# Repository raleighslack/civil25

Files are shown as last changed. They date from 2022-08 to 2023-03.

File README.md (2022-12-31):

# civil25 - An 8088 SBC  
A 8088 based SBC. 512k of RAM. 256k of ROM.

This is a simple 8088 based SBC that doesnt aim for any kind of PC compatibility. This is just generally a project to learn about the 8088 and other processors.

Current assembler in use is NASM. I am working on the **Currently in progress** goals listed below, as well as software to support it along the way.

## Current Parts List

- 1x 80c88 CPU
- 2x 74HCT373 D-type Octal Latch
- 1x 74HCT245 Bus Trancever
- 2x 74HCT138 3-to-8 Decoder
- 1x SST39SF020A Flash
- 1x AS6C4008 RAM
- 1x 82c55A PPI
- 1x 82c59 PIC
- 1x 555/8284 Clock Generator(And supporting circuitry)
- 1x YM3812 FM Sound
- 1x TL072 Op-Amp
- 1x Y3014B DAC
- 1x LCD
- 100000x Jumper Wires

# Completed

- Base Computer
- 82c55 I/O plus LCD
- YM3812
- Schematics

# Currently in progress

- 82c59 Programmable Interrupt Controller
- PS/2 Keyboard
- Video Card using SCN2674B
- Add SD Card
- Real Time Clock + Battery

# Future additions (Hardware)

- PCB - Mini ITX - Compatible with ATX PSU's
- Ethernet - Currently looking at the `W5100S-L`
- DMA Controller (82c57)
- Timer (82c53/82c54)
- CMOS RAM to maintain system settings

## Future Aditions (Software)

- C Compiler
- Make BIOS
- Make Kernel
- Make C Standard Library
- Make UNIX Operating System

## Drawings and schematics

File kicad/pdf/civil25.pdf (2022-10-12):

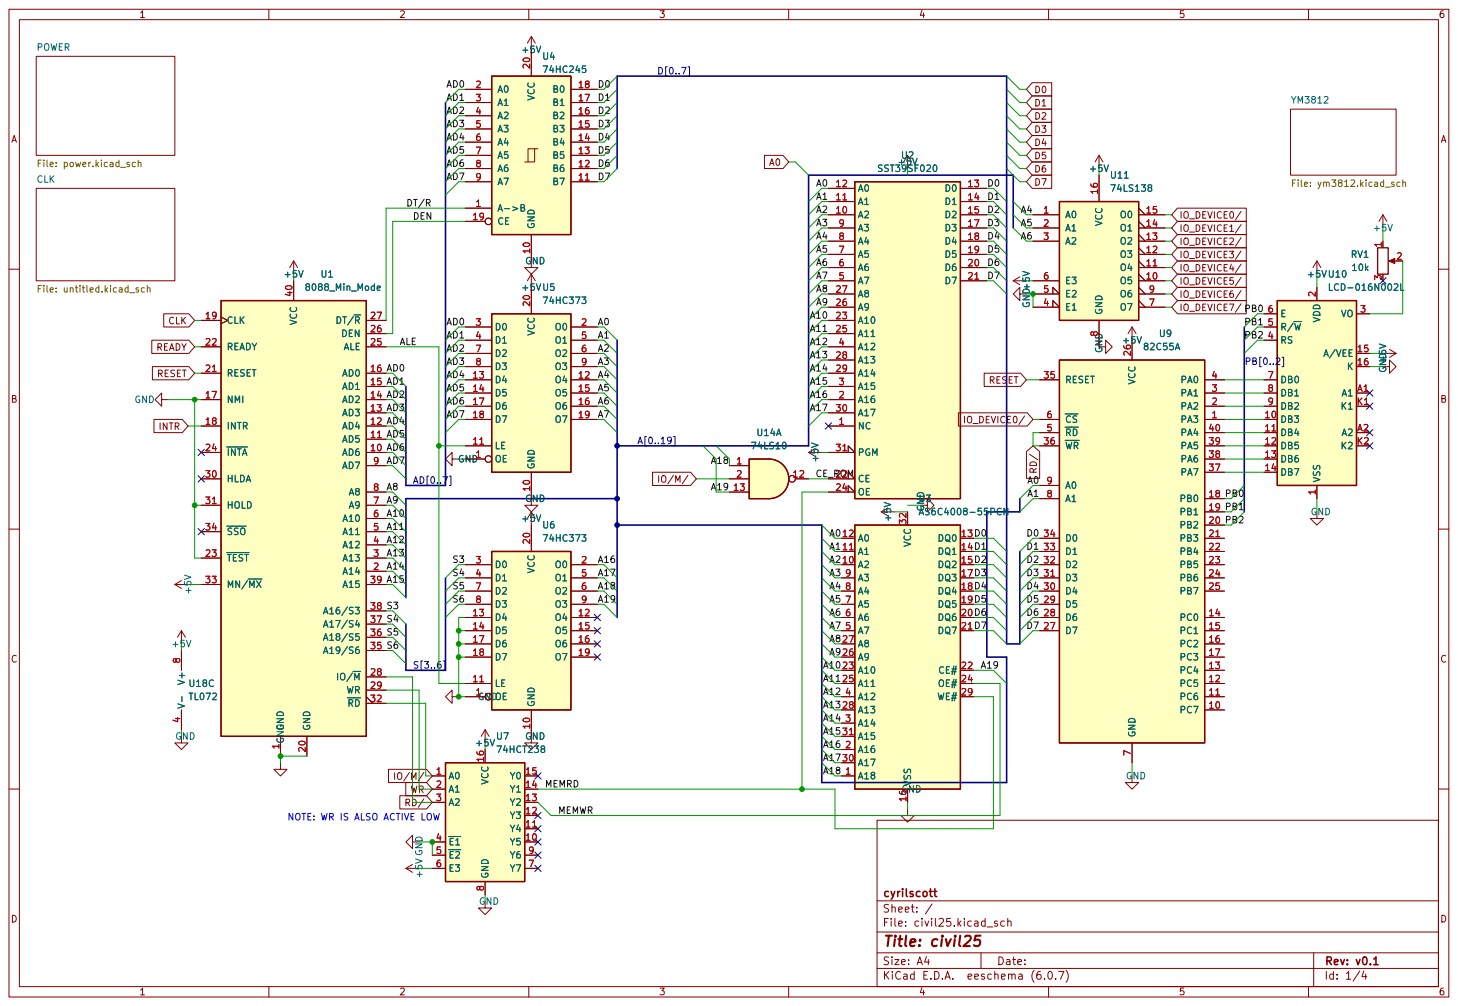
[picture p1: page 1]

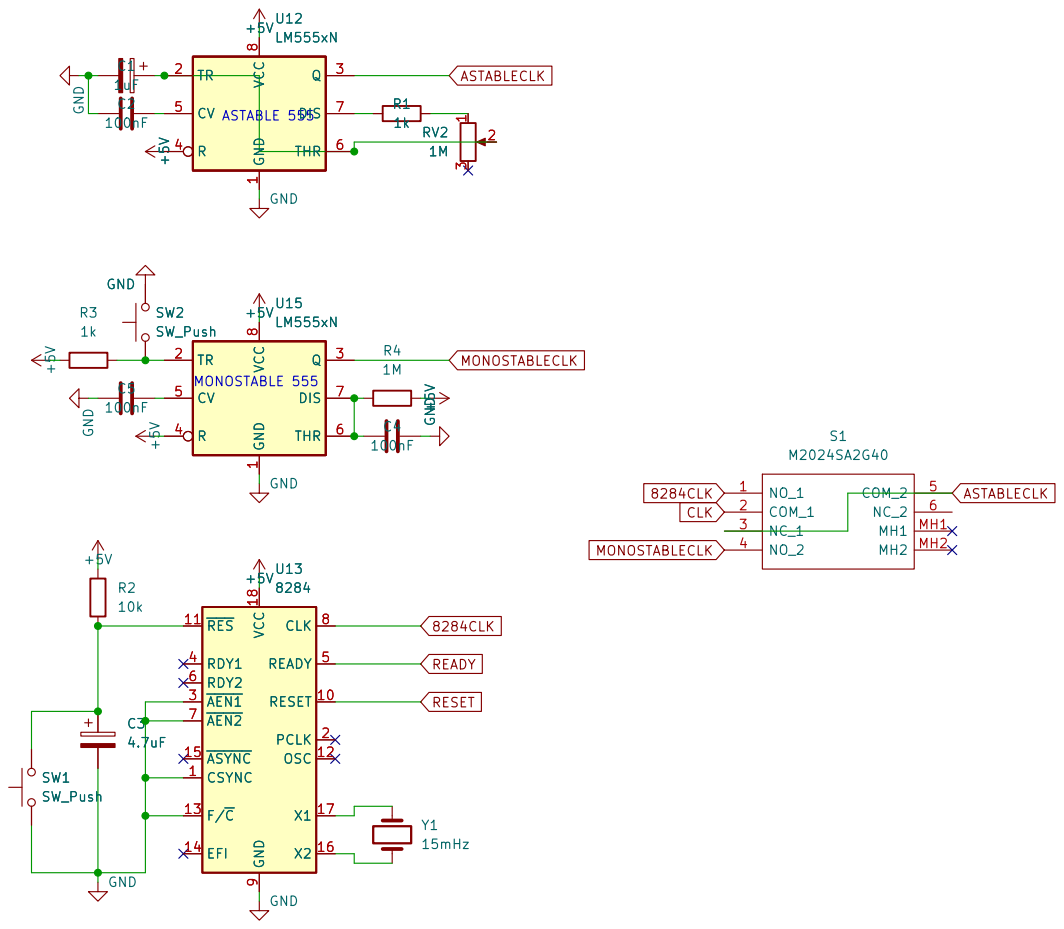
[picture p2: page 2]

8284CLK CLK MONOSTABLECLK MONOSTABLECLK MONOSTABLE 555 ASTABLE 555 GND
SW2 SW_Push GND

File: untitled.kicad_sch Sheet: /CLK/

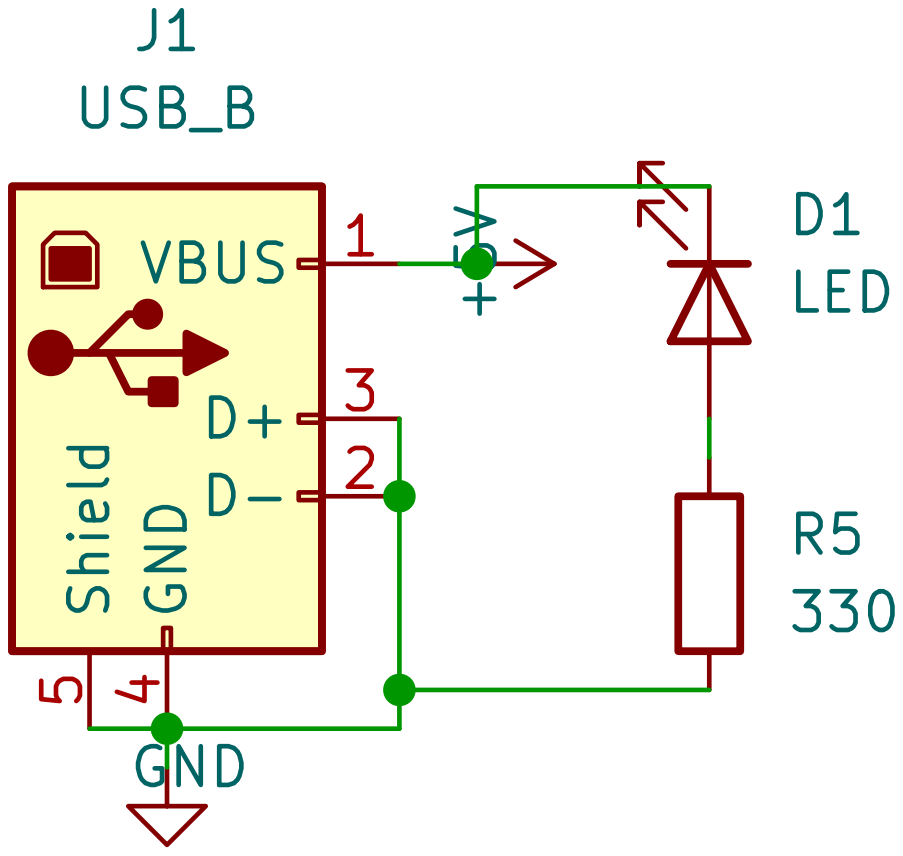
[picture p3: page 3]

File: power.kicad_sch Sheet: /POWER/ GND

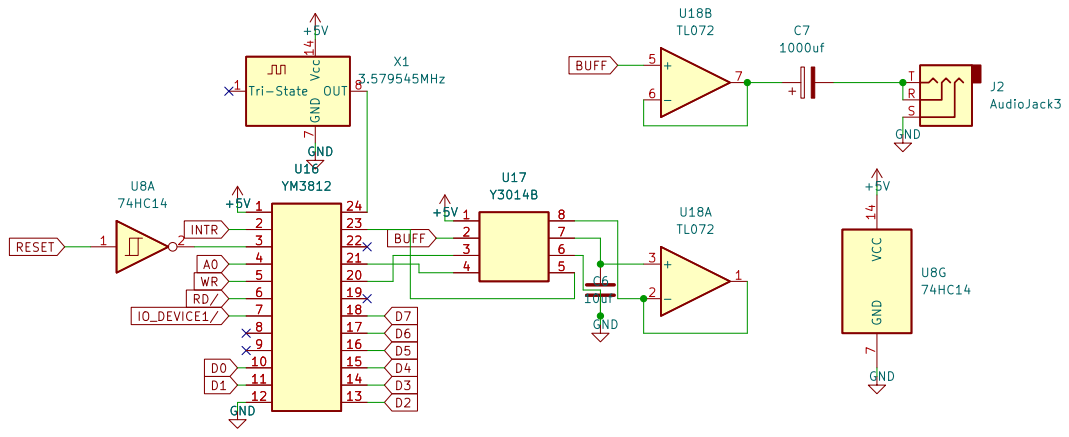
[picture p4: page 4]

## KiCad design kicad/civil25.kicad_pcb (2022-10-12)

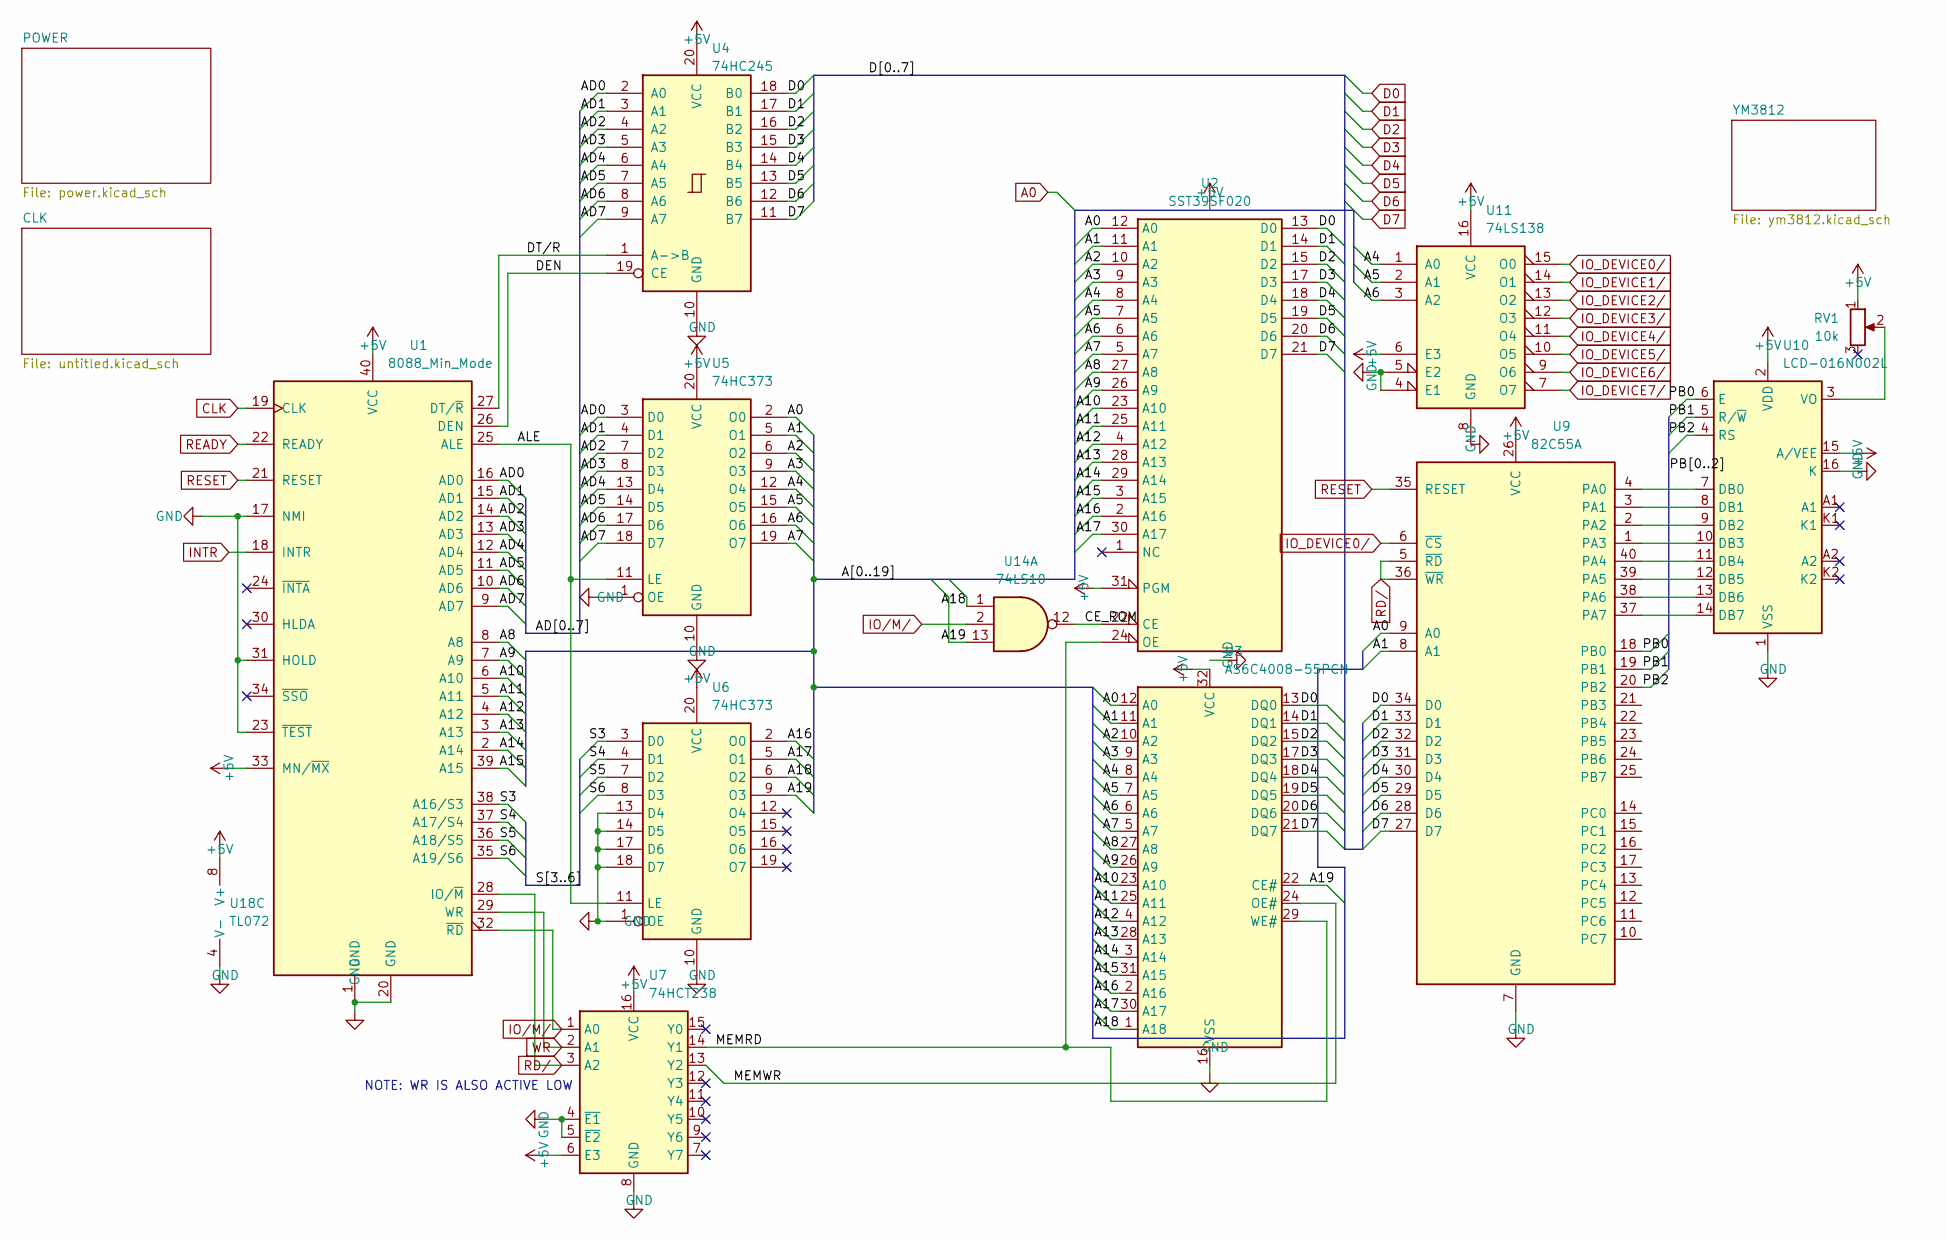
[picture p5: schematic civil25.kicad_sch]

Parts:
RV1: 10k; Potentiometer_ACP_CA9-V10_Vertical
U1: 8088_Min_Mode; DIP-40_W15.24mm
U2: SST39SF020; DIP_Socket-32_W11.9_W12.7_W15.24_W17.78_W18.5_3M_232-1285-0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
U3: AS6C4008-55PCN; DIP-32_W15.24mm
U4: 74HC245; DIP-20_W7.62mm_Socket
U5, U6: 74HC373; DIP-20_W7.62mm_Socket
U7: 74HCT238; DIP-16_W7.62mm_Socket
U9: 82C55A; DIP-40_W15.24mm
U10: LCD-016N002L; WC1602A
U11: 74LS138; DIP-16_W7.62mm_Socket
U14: 74LS10; DIP-14_W7.62mm_Socket
U18: TL072; DIP-8_W7.62mm_Socket

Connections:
+5V: RV1.1, U1.33 (MN/~MX), U1.40 (VCC), U2.31 (PGM), U2.32 (VCC), U3.32 (VCC), U4.20 (VCC), U5.20 (VCC), U6.20 (VCC), U7.6 (E3), U7.16 (VCC), U9.26 (VCC), U10.2 (VDD), U10.15 (A/VEE), U11.6 (E3), U11.16 (VCC), U18.8 (V+); also elsewhere on the board
/A1: U2.11 (A1), U3.11 (A1), U5.5 (O1), U9.8 (A1)
/A2: U2.10 (A2), U3.10 (A2), U5.6 (O2)
/A3: U2.9 (A3), U3.9 (A3), U5.9 (O3)
/A4: U2.8 (A4), U3.8 (A4), U5.12 (O4), U11.1 (A0)
/A5: U2.7 (A5), U3.7 (A5), U5.15 (O5), U11.2 (A1)
/A6: U2.6 (A6), U3.6 (A6), U5.16 (O6), U11.3 (A2)
/A7: U2.5 (A7), U3.5 (A7), U5.19 (O7)
/A8: U1.8 (A8), U2.27 (A8), U3.27 (A8)
/A9: U1.7 (A9), U2.26 (A9), U3.26 (A9)
/A10: U1.6 (A10), U2.23 (A10), U3.23 (A10)
/A11: U1.5 (A11), U2.25 (A11), U3.25 (A11)
/A12: U1.4 (A12), U2.4 (A12), U3.4 (A12)
/A13: U1.3 (A13), U2.28 (A13), U3.28 (A13)
/A14: U1.2 (A14), U2.29 (A14), U3.3 (A14)
/A15: U1.39 (A15), U2.3 (A15), U3.31 (A15)
/A16: U2.2 (A16), U3.2 (A16), U6.2 (O0)
/A17: U2.30 (A17), U3.30 (A17), U6.5 (O1)
/A18: U3.1 (A18), U6.6 (O2), U14.1
/A19: U3.22 (CE#), U6.9 (O3), U14.13
/AD0: U1.16 (AD0), U4.2 (A0), U5.3 (D0)
/AD1: U1.15 (AD1), U4.3 (A1), U5.4 (D1)
/AD2: U1.14 (AD2), U4.4 (A2), U5.7 (D2)
/AD3: U1.13 (AD3), U4.5 (A3), U5.8 (D3)
/AD4: U1.12 (AD4), U4.6 (A4), U5.13 (D4)
/AD5: U1.11 (AD5), U4.7 (A5), U5.14 (D5)
/AD6: U1.10 (AD6), U4.8 (A6), U5.17 (D6)
/AD7: U1.9 (AD7), U4.9 (A7), U5.18 (D7)
/ALE: U1.25 (ALE), U5.11 (LE), U6.11 (LE)
/CE_ROM: U2.22 (CE), U14.12
/DEN: U1.26 (DEN), U4.19 (CE)
/DT/R: U1.27 (DT/~R), U4.1 (A->B)
/MEMRD: U2.24 (OE), U3.29 (WE#), U7.14 (Y1)
/MEMWR: U3.24 (OE#), U7.13 (Y2)
/PB0: U9.18 (PB0), U10.6 (E)
/PB1: U9.19 (PB1), U10.5 (R/~W)
/PB2: U9.20 (PB2), U10.4 (RS)
/S3: U1.38 (A16/S3), U6.3 (D0)
/S4: U1.37 (A17/S4), U6.4 (D1)
/S5: U1.36 (A18/S5), U6.7 (D2)
/S6: U1.35 (A19/S6), U6.8 (D3)
A0: U2.12 (A0), U3.12 (A0), U5.2 (O0), U9.9 (A0); also elsewhere on the board
CLK: U1.19 (CLK); also elsewhere on the board
D0: U2.13 (D0), U3.13 (DQ0), U4.18 (B0), U9.34 (D0); also elsewhere on the board
D1: U2.14 (D1), U3.14 (DQ1), U4.17 (B1), U9.33 (D1); also elsewhere on the board
D2: U2.15 (D2), U3.15 (DQ2), U4.16 (B2), U9.32 (D2); also elsewhere on the board
D3: U2.17 (D3), U3.17 (DQ3), U4.15 (B3), U9.31 (D3); also elsewhere on the board
D4: U2.18 (D4), U3.18 (DQ4), U4.14 (B4), U9.30 (D4); also elsewhere on the board
D5: U2.19 (D5), U3.19 (DQ5), U4.13 (B5), U9.29 (D5); also elsewhere on the board
D6: U2.20 (D6), U3.20 (DQ6), U4.12 (B6), U9.28 (D6); also elsewhere on the board
D7: U2.21 (D7), U3.21 (DQ7), U4.11 (B7), U9.27 (D7); also elsewhere on the board
GND: U1.1 (GND), U1.17 (NMI), U1.20 (GND), U1.23 (~TEST), U1.31 (HOLD), U2.16 (GND), U3.16 (VSS), U4.10 (GND), U5.1 (OE), U5.10 (GND), U6.1 (OE), U6.10 (GND), U6.13 (D4), U6.14 (D5), U6.17 (D6), U6.18 (D7), U7.4 (~E1), U7.5 (~E2), U7.8 (GND), U9.7 (GND), U10.1 (VSS), U10.16 (K), U11.4 (E1), U11.5 (E2), U11.8 (GND), U18.4 (V-); also elsewhere on the board
INTR: U1.18 (INTR); also elsewhere on the board
IO_DEVICE0/: U9.6 (~CS), U11.15 (O0)
IO_DEVICE1/: U11.14 (O1); also elsewhere on the board
IO_DEVICE2/: U11.13 (O2)
IO_DEVICE3/: U11.12 (O3)
IO_DEVICE4/: U11.11 (O4)
IO_DEVICE5/: U11.10 (O5)
IO_DEVICE6/: U11.9 (O6)
IO_DEVICE7/: U11.7 (O7)
IO/M/: U1.32 (~RD), U7.1 (A0), U14.2
unnamed: RV1.2, U10.3 (VO)
unnamed: U9.4 (PA0), U10.7 (DB0)
unnamed: U9.3 (PA1), U10.8 (DB1)
unnamed: U9.2 (PA2), U10.9 (DB2)
unnamed: U9.1 (PA3), U10.10 (DB3)
unnamed: U9.40 (PA4), U10.11 (DB4)
unnamed: U9.39 (PA5), U10.12 (DB5)
unnamed: U9.38 (PA6), U10.13 (DB6)
unnamed: U9.37 (PA7), U10.14 (DB7)
RD/: U1.28 (IO/~M), U7.3 (A2), U9.5 (~RD), U9.36 (~WR); also elsewhere on the board
READY: U1.22 (READY); also elsewhere on the board
RESET: U1.21 (RESET), U9.35 (RESET); also elsewhere on the board
WR: U1.29 (WR), U7.2 (A1); also elsewhere on the board

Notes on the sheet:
NOTE: WR IS ALSO ACTIVE LOW

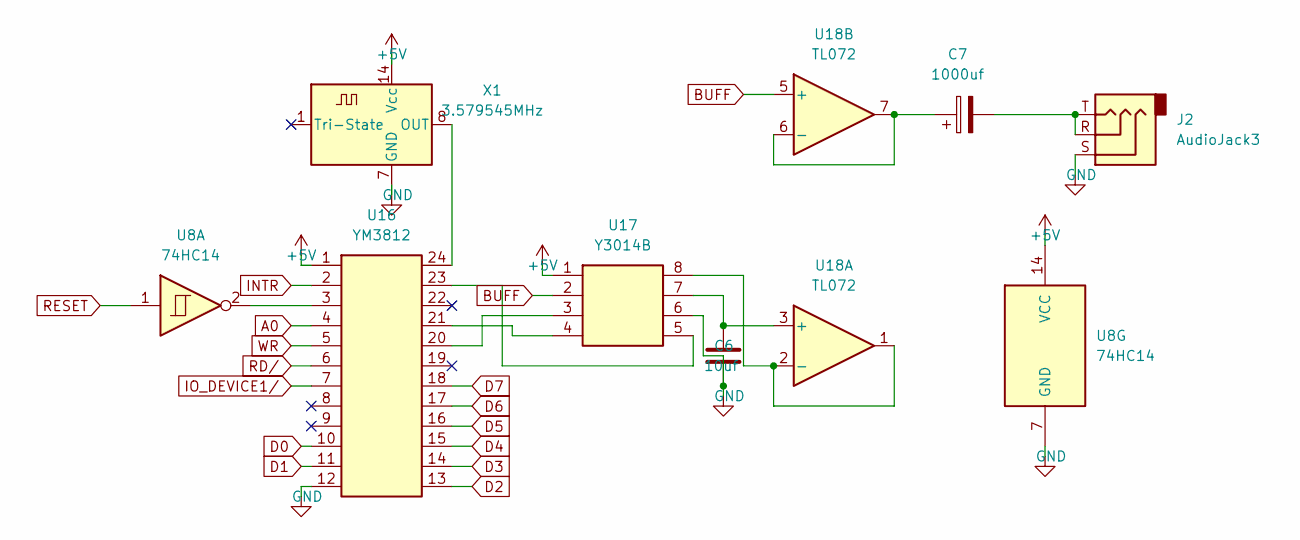
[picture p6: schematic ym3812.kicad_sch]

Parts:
C6: 10uf; CP_Radial_D5.0mm_P2.50mm
C7: 1000uf; CP_Radial_D5.0mm_P2.50mm
J2: AudioJack3; Jack_3.5mm_CUI_SJ1-3533NG_Horizontal_CircularHoles
U8: 74HC14; DIP-14_W7.62mm_Socket
U16: YM3812; DIP-24_W15.24mm_Socket
U17: Y3014B; DIP-8_W7.62mm_Socket
U18: TL072; DIP-8_W7.62mm_Socket
X1: 3.579545MHz; Oscillator_DIP-14

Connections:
+5V: U8.14 (VCC), U16.1, U17.1, X1.14 (Vcc); also elsewhere on the board
A0: U16.4; also elsewhere on the board
BUFF: U17.2, U18.5 (+)
D0: U16.10; also elsewhere on the board
D1: U16.11; also elsewhere on the board
D2: U16.13; also elsewhere on the board
D3: U16.14; also elsewhere on the board
D4: U16.15; also elsewhere on the board
D5: U16.16; also elsewhere on the board
D6: U16.17; also elsewhere on the board
D7: U16.18; also elsewhere on the board
GND: C6.2, J2.S, U8.7 (GND), U16.12, U17.6, X1.7 (GND); also elsewhere on the board
INTR: U16.2; also elsewhere on the board
IO_DEVICE1/: U16.7; also elsewhere on the board
unnamed: C6.1, U17.7, U18.3 (+)
unnamed: C7.1, U18.6 (-), U18.7
unnamed: C7.2, J2.R, J2.T
unnamed: U8.2, U16.3
unnamed: U16.20, U17.3
unnamed: U16.21, U17.4
unnamed: U16.23, U17.5
unnamed: U16.24, X1.8 (OUT)
unnamed: U17.8, U18.1, U18.2 (-)
RD/: U16.6; also elsewhere on the board
RESET: U8.1; also elsewhere on the board
WR: U16.5; also elsewhere on the board

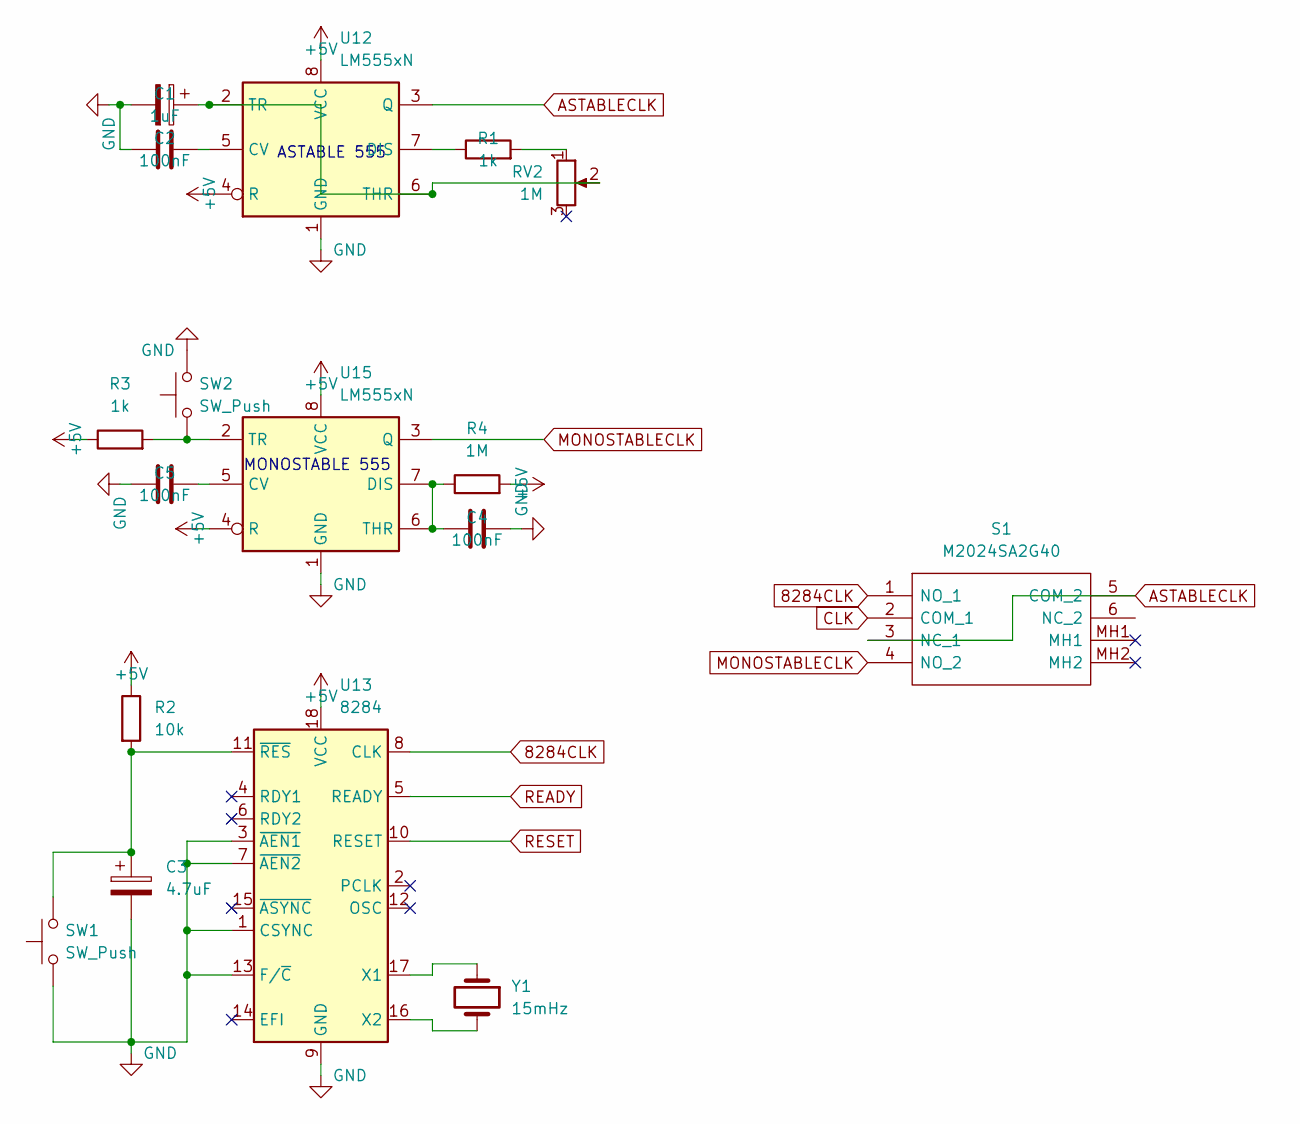
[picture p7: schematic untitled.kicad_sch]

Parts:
C1: 1uF; CP_Radial_D5.0mm_P2.50mm
C2, C4, C5: 100nF; C_Disc_D6.0mm_W2.5mm_P5.00mm
C3: 4.7uF; CP_Radial_D5.0mm_P2.50mm
R1, R3: 1k; R_Axial_DIN0204_L3.6mm_D1.6mm_P5.08mm_Horizontal
R2: 10k; R_Axial_DIN0204_L3.6mm_D1.6mm_P5.08mm_Horizontal
R4: 1M; R_Axial_DIN0204_L3.6mm_D1.6mm_P5.08mm_Horizontal
RV2: 1M; Potentiometer_ACP_CA9-V10_Vertical
S1: M2024SA2G40; Mouser Part Number 633-M2024SA2G40
SW1, SW2: SW_Push; SW_PUSH_6mm_H4.3mm
U12, U15: LM555xN; DIP-8_W7.62mm
U13: 8284; DIP-18_W7.62mm
Y1: 15mHz; Crystal_HC18-U_Vertical

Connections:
8284CLK: S1.1 (NO_1), U13.8 (CLK)
+5V: R2.1, R3.1, R4.2, U12.4 (R), U12.8 (VCC), U13.18 (VCC), U15.4 (R), U15.8 (VCC); also elsewhere on the board
ASTABLECLK: S1.3 (NC_1), S1.5 (COM_2), U12.3 (Q)
CLK: S1.2 (COM_1); also elsewhere on the board
GND: C1.2, C2.1, C3.2, C4.2, C5.1, SW1.1, SW2.2, U12.1 (GND), U13.1 (CSYNC), U13.3 (~AEN1), U13.7 (~AEN2), U13.9 (GND), U13.13 (F/~C), U15.1 (GND); also elsewhere on the board
MONOSTABLECLK: S1.4 (NO_2), U15.3 (Q)
unnamed: C1.1, RV2.2, U12.2 (TR), U12.6 (THR)
unnamed: C2.2, U12.5 (CV)
unnamed: C3.1, R2.2, SW1.2, U13.11 (~RES)
unnamed: C4.1, R4.1, U15.6 (THR), U15.7 (DIS)
unnamed: C5.2, U15.5 (CV)
unnamed: R1.1, U12.7 (DIS)
unnamed: R1.2, RV2.1
unnamed: R3.2, SW2.1, U15.2 (TR)
unnamed: U13.16 (X2), Y1.2
unnamed: U13.17 (X1), Y1.1
READY: U13.5 (READY); also elsewhere on the board
RESET: U13.10 (RESET); also elsewhere on the board

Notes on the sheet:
MONOSTABLE 555
ASTABLE 555

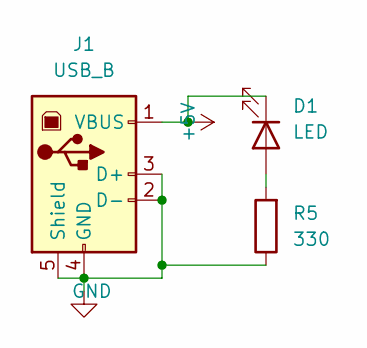
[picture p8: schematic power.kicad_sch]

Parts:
D1: LED; LED_D5.0mm
J1: USB_B; USB_B_Lumberg_2411_02_Horizontal
R5: 330; R_Axial_DIN0204_L3.6mm_D1.6mm_P5.08mm_Horizontal

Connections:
+5V: D1.1 (K), J1.1 (VBUS); also elsewhere on the board
GND: J1.2 (D-), J1.3 (D+), J1.4 (GND), J1.5 (Shield), R5.1; also elsewhere on the board
unnamed: D1.2 (A), R5.2

Board: 2 copper layers, 40 parts (0 on the bottom side), 93 nets, no tracks yet.

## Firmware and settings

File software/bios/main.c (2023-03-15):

#include <lcd.h>
#include <utils.h>
#include <stdbool.h>
#include <stdint.h>
#include <string.h>
#include <stdlib.h>
#include <key8242.h>
#define _OPEN_SYS_ITOA_EXT

void lcd_init()
{
	lcd_function_set(true, true, false);   // Set 8 bit mode, 2-line display, 5x8 font
	lcd_display_control(true, true, true); // Display on, cursor on, blink on
	lcd_entry_mode(true, false);		   // Increment and shift cursor; don't shift display
	lcd_return_home();
}

bool checkMemory()
{
	uint16_t ramSize = ramtest();

	if (!ramSize || ramSize != 512)
		return EXIT_FAILURE;

	return EXIT_SUCCESS;
}

void main() // does memtest and prints out 512K
{
	lcd_init();

	if (checkMemory() != EXIT_SUCCESS)
	{
		lcd_print_string("No memory!");
	}

	lcd_print_string("Hello, World!");
}

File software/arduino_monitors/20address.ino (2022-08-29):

const char ADDR[] = {22, 24, 26, 28, 30, 32, 34, 36, 38, 40, 42, 44, 46, 48, 50, 52, 31, 33, 35, 37};
// const char DATA[] = {39, 41, 43, 45, 47, 49, 51, 53};
#define CLOCK 2
#define READ_WRITE 3

void setup()
{
    for (int n = 0; n < 20; n += 1)
    {
        pinMode(ADDR[n], INPUT);
    }
    pinMode(CLOCK, INPUT);
    pinMode(READ_WRITE, INPUT);

    attachInterrupt(digitalPinToInterrupt(CLOCK), onClock, RISING);

    Serial.begin(57600);
}

void onClock()
{
    char output[19];

    unsigned int address = 0;
    for (int n = 0; n < 20; n += 1)
    {
        int bit = digitalRead(ADDR[n]) ? 1 : 0;
        Serial.print(bit);
        address = (address << 1) + bit;
    }

    Serial.print("   ");

    sprintf(output, "   %05x %c", address, digitalRead(READ_WRITE) ? 'r' : 'W');
    Serial.println(output);
}

void loop() {}

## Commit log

2022-08-29 add arduino monitors
2022-10-12 remove unused assemblers/update gcc
    [civil25.kicad_sch]
2022-10-12 update PCB
    [civil25.kicad_pcb, civil25.kicad_sch, power.kicad_sch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]
2022-12-23 stable
    Current, stable code
2022-12-30 Working print string
